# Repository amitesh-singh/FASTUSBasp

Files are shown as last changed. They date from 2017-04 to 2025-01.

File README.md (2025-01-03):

"Buy Me A Coffee" (https://www.buymeacoffee.com/singhamiteK)

### FASTUSBasp programmer for AVR Microcontrollers


This is the fast ISP programmer for AVR MCUs based on cheap stm32f103c8t6 aka `blue-pill` board with usb-to-serial support.

### Release

- v1.0.0:  https://github.com/amitesh-singh/FASTUSBasp/releases/tag/v1.0.0

#### FastUSBASPv2 board
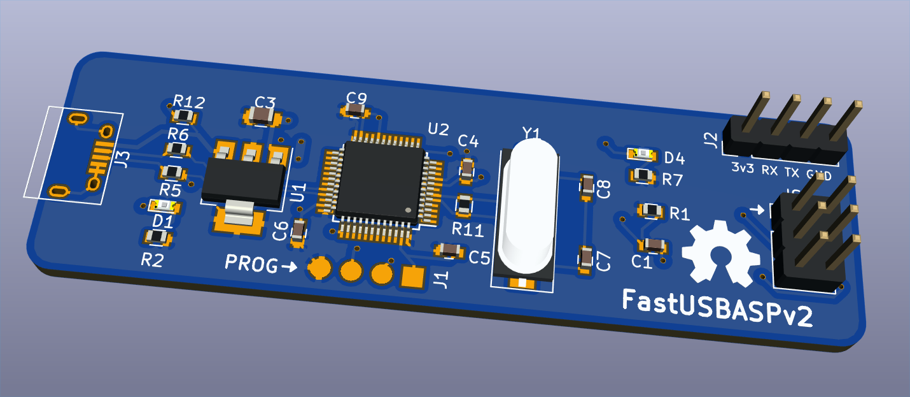
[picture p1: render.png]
FastUSBASPv2 board


#### Perf board
perfboard

### Correcting wrong pullup at USB D+

This blue pill board has wrong pullup resistor at usb D+ line.
You might need to fix it before using blue pill as an AVR programmer.
Refer to this guide: [http://amitesh-singh.github.io/stm32/2017/10/09/correcting-usbpullup-resistor.html][fixpullup-link]

### how to upload firmware

#### blue pill board with correct pullup at USB D+ line
 Download the binaries from https://github.com/amitesh-singh/FASTUSBasp/releases/tag/v1.0.0

If you have fixed the pullup at D+ line, use `fastusbasp.bin`
The pre-compiled binary is at `fastusbasp.bin`.

```shell
$ st-flash write fastusbasp.bin 0x08000000
```

#### blue pill board with wrong pullup at USB D+ line
In case, you did not fix the wrong pullup at D+ line, use
`fastusbasp-wrongpullup.bin` binary instead

```shell
$ st-flash write fastusbasp-wrongpullup.bin 0x08000000
```

### How to use

#### ISP connections

It uses SPI2 to communicate to AVR.

Blue pill | AVR
--------- | -------
PB15  |   MOSI
PB14  |   MISO
PB13  |   SCK
PA8   |   RST
5v or 3.3v |     5v
GND        |    GND

#### Serial connections
Serial ports are `PA10`(RX) and `PA9` (TX).
This can be used to debug AVR Microcontrollers.

Blue pill | AVR
--------- | -------
PA10      | TX
PA9       | RX

All pins SPI2(PB15, PB14, PB13), Serial(PA10, PA9) and RST(PA8) used are 5V tolerant.

#### udev rule

Refer to [udev/README.md](udev/README.md)

### On plugging to PC
#### Linux
When you plug this device to PC, you should get following message on`dmesg -wH`

```shell
[Jan20 13:31] usb 3-1.1: new full-speed USB device number 5 using xhci_hcd
[  +0.107774] usb 3-1.1: New USB device found, idVendor=16c0, idProduct=05dc
[  +0.000004] usb 3-1.1: New USB device strings: Mfr=1, Product=2, SerialNumber=3
[  +0.000002] usb 3-1.1: Product: fastusbasp
[  +0.000002] usb 3-1.1: Manufacturer: http://amitesh-singh.github.io
[  +0.000001] usb 3-1.1: SerialNumber: AARAV
[  +0.040797] cdc_acm 3-1.1:1.0: ttyACM0: USB ACM device
[  +0.000804] usbcore: registered new interface driver cdc_acm
[  +0.000000] cdc_acm: USB Abstract Control Model driver for USB modems and ISDN adapters
```

`/dev/ttyACM0` is the serial port.

#### Windows
- Download Zadig (https://zadig.akeo.ie/)
- Insert device to USB. Wait until windows can't install it.
- Launch Zadig
- Select in Zadig our device from ComboBox
- Select driver Type libusbK
- Press Install Driver
- Wait until Zadig is done with installing driver and that results into Windows to detect the device.

### Probe AVR

```shell
$ avrdude -c usbasp-clone -p m16

avrdude: AVR device initialized and ready to accept instructions

Reading | ################################################## | 100% 0.00s

avrdude: Device signature = 0x1e9403 (probably m16)

avrdude: safemode: Fuses OK (E:FF, H:D8, L:CF)

avrdude done.  Thank you.
```

### Upload program to AVR

```shell
$ avrdude -c usbasp-clone -p m16 -U flash:w:blink.hex

avrdude: AVR device initialized and ready to accept instructions

Reading | ################################################## | 100% 0.00s

avrdude: Device signature = 0x1e9403 (probably m16)
avrdude: NOTE: "flash" memory has been specified, an erase cycle will be performed
         To disable this feature, specify the -D option.
avrdude: erasing chip
avrdude: reading input file "blink.hex"
avrdude: input file blink.hex auto detected as Intel Hex
avrdude: writing flash (150 bytes):

Writing | ################################################## | 100% 0.02s

avrdude: 150 bytes of flash written
avrdude: verifying flash memory against blink.hex:
avrdude: load data flash data from input file blink.hex:
avrdude: input file blink.hex auto detected as Intel Hex
avrdude: input file blink.hex contains 150 bytes
avrdude: reading on-chip flash data:

Reading | ################################################## | 100% 0.01s

avrdude: verifying ...
avrdude: 150 bytes of flash verified

avrdude: safemode: Fuses OK (E:FF, H:D8, L:CF)

avrdude done.  Thank you.

```

### Read flash
```shell
$ avrdude -c usbasp-clone -p m16 -U flash:r:flash.bin:r

avrdude: AVR device initialized and ready to accept instructions

Reading | ################################################## | 100% 0.00s

avrdude: Device signature = 0x1e9403 (probably m16)
avrdude: reading flash memory:

Reading | ################################################## | 100% 0.33s

avrdude: writing output file "flash.bin"

avrdude: safemode: Fuses OK (E:FF, H:D8, L:CF)

avrdude done.  Thank you.

$ hexdump flash.bin
0000000 c029 0000 c02f 0000 c02d 0000 c02b 0000
0000010 c029 0000 c027 0000 c025 0000 c023 0000
0000020 c021 0000 c01f 0000 c01d 0000 c01b 0000
0000030 c019 0000 c017 0000 c015 0000 c013 0000
0000040 c011 0000 c00f 0000 c00d 0000 c00b 0000
0000050 c009 0000 2411 be1f e5cf e0d4 bfde bfcd
0000060 d002 c017 cfcd 9ab8 9ac0 ef2f ed83 e390
0000070 5021 4080 4090 f7e1 c000 0000 98c0 ef2f
0000080 ed83 e390 5021 4080 4090 f7e1 c000 0000
0000090 cfeb 94f8 cfff

```

### Flash Read/Write speed

Flash Write speed: 15 KBps
Flash Read Speed: 52.5 KBps

### Bit clock speed
`FASTUSBasp` starts out with a fast ISP clock frequency (default: 3 MHz),
   so the `-B bitclock` option might be required to achieve stable communication
in case target MCU `F_CPU` is bit low < 12MHz
#### Supported bitclock speed

- default (without -B): 3 MHz
- 1.5 MHz
- 750 KHz
- 375 KHz
- 187.5 KHz

### how to compile from source and upload the firmware
To build fastusbasp firmware from source code, follow below guidelines.

#### compile
Refer my post on how to setup stm32 devlopment environment on Arch linux.
http://amitesh-singh.github.io/stm32/2017/04/09/setting-stm32-dev-environment-arch-linux.html

Make sure you have compiled `libopencm3` library.

```shell
$ git clone --recurse-submodules https://github.com/amitesh-singh/FASTUSBasp
$ mkdir build
$ cd build
$ cmake ../
$ make
```
#### Upload the firmware
##### using STLINK
###### with st-flash
connect `st-link` programmer to `blue-pill` and upload the firmware

```shell
$ make fastusbasp-upload

```

###### with openocd

```shell
$ make fasusbasp-ocdupload

```

##### using serial port

Install `stm32flash` utility on linux.
To program `stm32f103` via USART, you need to set `BOOT0` as `1`
and leave `BOOT1` as `0`.

Connect any usb to uart converter device and connect PA9 to RXD and PA10 to TXD
and connect GND.

```shell
$ make fastusbasp-serialupload

```

### Links

- http://amitesh-singh.github.io/stm32/2017/05/21/FASTUSBasp-programmer-avr.html
- https://hackaday.io/project/21189-fastusbasp-programmer-for-avr

[fixpullup-link]: http://amitesh-singh.github.io/stm32/2017/10/09/correcting-usbpullup-resistor.html

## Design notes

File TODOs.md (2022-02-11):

### TODOs

- ~~support more speed.~~  
  avrdude -B 0.5/0.2 ..
- ~~Add kicad schematics for adapter board.~~
- ~~Add kicad gerber files for adapter board.~~
- ~~Add panelized pcb design and gerber files~~
- support TWI to support attiny
- Blink LED while flashing

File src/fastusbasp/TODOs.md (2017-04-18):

### TODOs

- ~~support more speed.~~  
  avrdude -B 0.5/0.2 ..
- ~~Add kicad schematics for adapter board.~~
- ~~Add kicad gerber files for adapter board.~~
- ~~Add panelized pcb design and gerber files~~
- Try to put 4 boards into 100x100mm area to save cost.

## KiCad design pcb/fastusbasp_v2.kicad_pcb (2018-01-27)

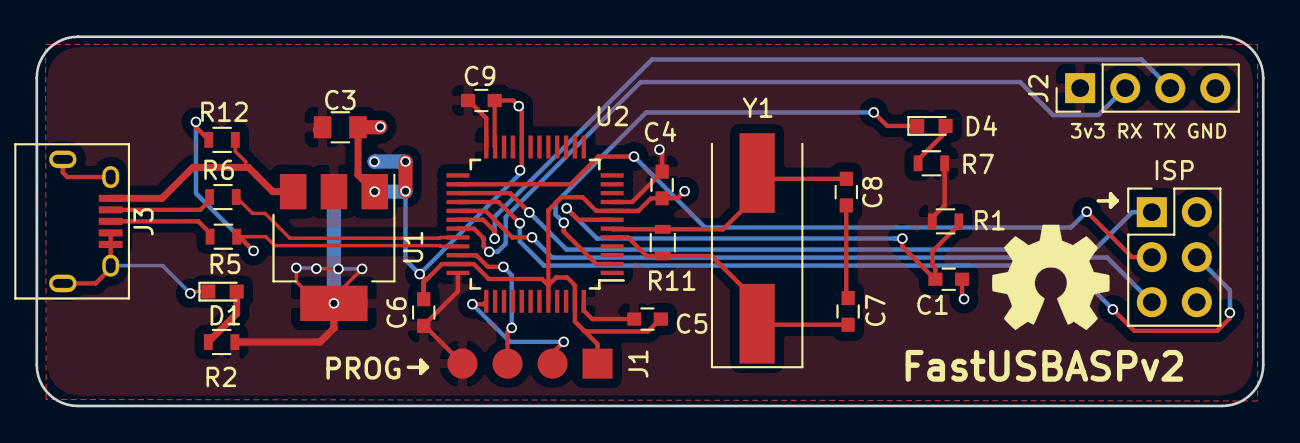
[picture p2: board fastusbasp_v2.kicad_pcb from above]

Board: 2 copper layers, 69.2 x 20.8 mm, 24 parts (0 on the bottom side), 22 nets.

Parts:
C1: 100nF; C_0603
C3: 10uF; C_0805
C4, C5, C6, C9: 100nf; C_0603
C7, C8: 20pF; C_0603
D1, D4: LED; LED_0603
ISP: AVR-ISP-6; Pin_Header_Straight_2x03_Pitch2.54mm
J1: PROG; Pin_Header_SMD_pads_1x04_pitch2.54mm
J2: CONN_01X04; Pin_Header_Straight_1x04_Pitch2.54mm
J3: USB_OTG; USB_Micro-B
R1: 10k; R_0603
R2, R7: 1k; R_0603
R5, R6: 20R; R_0603
R11: 1M; R_0603
R12: 1.5k; R_0603
U1: LM1117-3.3; SOT-223-3_TabPin2
U2: STM32F103C8Tx; LQFP-48_7x7mm_Pitch0.5mm
Y1: 16MHz; Crystal_SMD_HC49-SD

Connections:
+3V3: C3.1, C4.1, C5.1, C6.1, C9.1, J1.4, J2.1, R1.1, R2.2, R7.2, U1.2, U2.9, U2.24, U2.36, U2.48
+5V: J3.1, R12.2, U1.3
/D_N: R6.1, U2.32
/D_P: R5.1, R12.1, U2.33
/ISP_MISO: ISP.1, U2.27
/ISP_MOSI: ISP.4, U2.28
/ISP_RESET: ISP.5, U2.29
/ISP_SCK: ISP.3, U2.26
/PGM_LED: D4.1, U2.2
/RESET: C1.1, R1.2, U2.7
/RXD: J2.2, U2.31
/SWCLK: J1.2, U2.37
/SWDIO: J1.3, U2.34
/TXD: J2.3, U2.30
GND: C1.2, C3.2, C4.2, C5.2, C6.2, C9.2, D1.1, ISP.6, J1.1, J2.4, J3.4, J3.5, J3.6, U1.1, U2.8, U2.20, U2.23, U2.35, U2.44, U2.47
unnamed: C7.1, R11.1, U2.5, Y1.1
unnamed: C7.2, C8.2
unnamed: C8.1, R11.2, U2.6, Y1.2
unnamed: D1.2, R2.1
unnamed: D4.2, R7.1
unnamed: J3.2, R6.2
unnamed: J3.3, R5.2

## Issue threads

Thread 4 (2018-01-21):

Verify FASTUSBasp on Windows OS

amitesh-singh, 2018-01-21:
I don't own a windows PC at home. It would be nice if someone helps in validating FASTUSBasp on windows OS.

posystorage, 2018-02-02:
Hello, I try to burn the firmware (in stm32f103rct6, either fastusbasp.bin or fastusbasp-wrongpullup.bin) In the windows PC, the system shows usb get description failed (configuration descriptor is invalid)
This is the usb descriptor file
[fastusbasp  usb description.txt](https://github.com/amitesh-singh/FASTUSBasp/files/1688455/fastusbasp.usb.description.txt)
I think it may be missing the CDC Interface Descriptor and Endpoint Descriptor

I tried define USBDPLUS_WRONG_PULLUP=1
and modified the code here
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
However it also did not work

posystorage, 2018-02-02:
this is the usb enumeration process data which obtained by using the logic analyzer
[untitled.txt](https://github.com/amitesh-singh/FASTUSBasp/files/1688517/untitled.txt)

amitesh-singh, 2018-02-02:
Thanks.
do you have installed usb driver on windows?

Try following driver

http://zadig.akeo.ie/

posystorage, 2018-02-02:
I have installed the usb driver, and it works fine when using the "fastusbasp v1" firmware.

I get another PC which is  windows7 OS,it works fine，no matter which firmware it is（v1 or v2）
But v2 firmware does not work in  windows10

amitesh-singh, 2018-02-02:
Thanks for the detailed report.
Firmware V1 & V2 works on Windows 7 OS
Firmware V1 works on Windows 10 but Firmware V2 does not work on windows 10.
The difference between firmware V1 & v2 is the addition of USB-CDC(usb serial) into V2.

Sorry, I don't have any device running windows 7 or 10. This might needs to be checked by some Windows OS expert.

posystorage, 2018-02-02:
I analyzed the enumeration process and found that after the host requested the configuration descriptor, the device seems like returned the wrong configuration description data.
So when Windows received the wrong configuration descriptor, the system reset the usb bus, re-enumeration,  error again, after three consecutive errors, the enumeration failed.

another a problem, v2 firmware should enumerate two usb devices: serial port (VCP) and FASTUSBasp, but even in the Windows7 OS, it can only enumerate FASTUSBasp, but no serial port.

posystorage, 2018-02-02:
I think there is something wrong with the content of configuration descriptors
It is not standard, so that some OS do not recognize it, and some OS ignore these problems
for example：
v2 firmware configuration description
	bLength=0x0D
	bDescriptorType=0x02 CONFIGURATION
	wTotalLength=0x0094
	bNumInterfaces=0x03
	bConfigurationValue=0x01
	iConfiguration=0x00
	bmAttributes=0x80 Bus powered, Remote wakeup unsupported
	bMaxPower=0x32 100mA
	byte=0xD8
	byte=0x25
	byte=0x00
	byte=0x08
        bLength=0x08
	bDescriptorType=0x0B <unknown>
	byte=0x00
	byte=0x02
	byte=0x02
	byte=0x02
	byte=0x01
	byte=0x00
...........

USB standard configuration description should be
    /*Configuration Descriptor*/
    0x09,   /* bLength: Configuration Descriptor size */
    USB_CONFIGURATION_DESCRIPTOR_TYPE,      /* bDescriptorType: Configuration  0x02 */
    0x27,       /* wTotalLength:no of returned bytes */
    0x00,
    0x01,   /* bNumInterfaces: 1 interface */
    0x01,   /* bConfigurationValue: Configuration value */
    0x00,   /* iConfiguration: Index of string descriptor describing the configuration */
    0x80,   /* bmAttributes: self powered */
    0x32,   /* MaxPower 32 mA */
    /*Interface Descriptor*/
    0x09,   /* bLength: Interface Descriptor size */
    USB_INTERFACE_DESCRIPTOR_TYPE,  /* bDescriptorType: Interface */
    /* Interface descriptor type */
    0x00,   /* bInterfaceNumber: Number of Interface */
    0x00,   /* bAlternateSetting: Alternate setting */
    0x03,   /* bNumEndpoints: 3 endpoints used */
    0xff,   /* bInterfaceClass: Communication Interface Class */
    0xff,   /* bInterfaceSubClass: Abstract Control Model */
    0xff,   /* bInterfaceProtocol: Common AT commands */
    0x04,   /* iInterface: */
...........

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
Universal Serial Bus Specification Revision 2.0
page 265

I use the STM32F10x standard peripheral library and STM32F10x USB full-speed device library which is official library by STMicroelectronics ，so it is hard for me to understand the libopencm3 .It contains too many files, let me feel faint

So I hope to get your help, thanks.

amitesh-singh, 2018-02-04:
I got some pointers regarding fixing endpoints in usb cdc descriptor. I shall give it a try this week when i get time.

Thanks a lot to provide detailed debug informations.

amitesh-singh, 2018-02-08:
i pushed a small fix.

could you please try with this fix?
you do need to rebuild the project.

https://github.com/amitesh-singh/FASTUSBasp/commit/adf6f53b29b1322804abe90e93d6fa5eb1e4fa49
Please let me know if it solves the issue.

posystorage, 2018-02-09:
I just tried it.It did not work.😫

cdtsilva, 2019-02-26:
Can someone post a copy of the V1 firmware (no serial) that is supposed to work on Win10?

f4grx, 2019-03-12:
since this is a composite device, windows probably needs an .inf file to be able to manage both the fastusbasp (what is it ? HID?) AND the CDC ACM Virtual com port.

seaspacio, 2019-10-26:
can you please provide a V1 compiled firmware?

binarymaker, 2019-10-30:
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
In windows8 also not work. i tried master and cdc-fix branches.

Spider84, 2020-05-26:
Hello! I has fixed this issue: https://github.com/amitesh-singh/FASTUSBasp/pull/8

amitesh-singh, 2020-05-29:
Thanks to this patch, https://github.com/amitesh-singh/FASTUSBasp/commit/8e50587327878244815f05512673f850ab48613e,
by @Spider84 , FASTUSBasp is supported on Windows.

Spider84, 2020-05-29:
Glad to help. Thx for firmware. Very helped me to flash single AVR in my STM32 world :)

Closed 2020-05-29.

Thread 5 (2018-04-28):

Reset after programming

mkSaBtsy, 2018-04-28:
First to say: Great project.
FASTUSBasp is way faster than my AVRISPmkII clone which I couldn't get working under Win7-64 anyway.

Now my issue:
I'm using AVRDUDESS / Win7-64 to program an ATmega328p. Everything is working well.
But after any action the reset line stays low, keeping the microcontroller in reset state. What I'm doing wrong?
Please help.

amitesh-singh, 2018-04-28:
Hello
Thanks for the feedback. It seems like a bug.
I should set the RST pin to input on disconnect.

amitesh-singh, 2018-04-28:
Hello again,

i added the fix and updated the binaries too.
Please let me know if it fixes the issue.

https://github.com/amitesh-singh/FASTUSBasp/commit/8fc50ff744d3d3653f113068feb581d30c6b52c3

Thanks

mkSaBtsy, 2018-04-28:
Hello
Thanks a lot for the fast update. I flashed new firmware with ST-Link but unfortunately the RST line keeps low again.

mkSaBtsy, 2018-04-29:
Shouldn't you use
`rst.setMode(PinMode::INPUT, PinConfig::INPUT_FLOAT);`
instead of
`rst.setMode(PinMode::OUTPUT_2MHZ, PinConfig::INPUT_FLOAT);`
?
For pins mosi and sck this would apply too.
Can you change this and compile again? I'm new to ARM programming and not able to set up the project in Eclipse (under Windows) properly.

amitesh-singh, 2018-04-29:
Oops.. good catch .. i will update the code and binary.
Thanks.

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

amitesh-singh, 2018-04-30:
i updated the binaries and code. please check it again.

mkSaBtsy, 2018-04-30:
Dear Amitsh Singh
Now FastUSBasp works like a charm. Thumbs up.

In the mean time (since you uploaded the new binaries not necessary anymore) I tried to build FASTUSBasp on a fresh installed VM Ubuntu Linux. Do you know, if there's a difference between arch linux and ubuntu when disabling standard paths? Libopencm3 compiles without a problem but when linking FASTUSBasp make complains about missing libopencmw_stm32f1.ld file which is in FASTUSBasp directory.

Anyway. Many thanks for this great project.

amitesh-singh, 2018-05-01:
Or you can create separate md file (say windows.md) for guide.

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

mkSaBtsy, 2018-05-03:
Hello
I tried again to compile with fresh installed Ubuntu 18.04:

- [x] sudo apt-get update
- [x] sudo apt-get upgrade
- [x] sudo apt-get install git cmake make python gcc-arm-none-eabi
- [x] git clone https://github.com/libopencm3/libopencm3)
- [x] cd libopencm3
- [x] make
->compiles without problem

- [x] git clone https://github.com/amitesh-singh/FASTUSBasp
- [x] cd FASTUSBasp
- [x] nano config.cmake
->set(LIBOPENCM3_DIR "/home/mksabtsy/libopencm3")
- [x] cmake .
cmake . ends up in 4 warnings concerning deprecation (see attached screenshot)
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

- [x] make

-> as far as I can see, building works, but linking fails because of missing libopencm3_stm32f1.ld file.

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

libopencm3_stm32f1.ld is located in FASTUSBasp directory (.). I guess unlinking system paths does not work properly.

Now I'm short of time, but I could write a short instruction how to use FASTUSBasp with Win7/64. Maybe later even for Win10/64.
What about the pull request? Should I place my instructions there?

amitesh-singh, 2018-05-08:
Yes. please provide a pull request regarding the instructions for windows setup.

amitesh-singh, 2018-06-03:
Hi,

I fixed the compilation issue on Ubuntu.
Refer to https://github.com/amitesh-singh/FASTUSBasp/commit/e4bc3f48ea11e421ee3d1f94b6a9a09a7d714ec1

Closed 2018-04-28.

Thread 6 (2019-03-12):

Make it work on any machine

f4grx, 2019-03-12:
Hello,
wanted to build it, but:

```
me@machine~/code/fastusbasp $ cat config.cmake
# Always declare this before stm32-toolchain.cmake
#
set(MCU STM32F1)
set(LIBOPENCM3_DIR "/home/ami/repos/libopencm3")
set(SERIAL_PORT "/dev/ttyUSB0")
```
No chance this will work here :)

Can you include libopencm3 in your source tree, or manage it as a configurable dependency via, eg, a cmake variable?

thanks

f4grx, 2019-03-12:
OK, config.cmake works for this

however now I get this:
```
[ 75%] Linking CXX executable fastusbasp.elf
cd /home/user/code/fastusbasp/src && /usr/bin/cmake -E cmake_link_script CMakeFiles/fastusbasp.dir/link.txt --verbose=1
/home/user/toolchains/gcc-arm-none-eabi-7-2018-q2-update/bin/arm-none-eabi-g++    -fdata-sections -ffunction-sections -fno-exceptions -Wall --std=gnu++14 -Os -ggdb -mcpu=cortex-m3 -mthumb -mthumb-interwork -msoft-float -Wextra -Wshadow -Wredundant-decls    -flto -T /home/user/code/fastusbasp/libopencm3.ld -nostartfiles -lopencm3_stm32f1 -lc -specs=nosys.specs -Wl,--gc-sections -Wl,--relax CMakeFiles/fastusbasp.dir/main.cpp.obj  -o fastusbasp.elf  -L/home/user/code/libopencm3/lib  -L/home/user/code/libopencm3/lib/stm32/f1 -lopencm3_stm32f1 -L/home/user/code/fastusbasp/src/../lib/ ../lib/libstm32f1cpp.a -lopencm3_stm32f1
/home/user/toolchains/gcc-arm-none-eabi-7-2018-q2-update/bin/../lib/gcc/arm-none-eabi/7.3.1/../../../../arm-none-eabi/lib/thumb/v7-m/libc.a(lib_a-fini.o): In function `__libc_fini_array':
fini.c:(.text.__libc_fini_array+0x26): undefined reference to `_fini'
collect2: error: ld returned 1 exit status
src/CMakeFiles/fastusbasp.dir/build.make:95: recipe for target 'src/fastusbasp.elf' failed
```

It seems related to this:
https://bugs.launchpad.net/gcc-arm-embedded/+bug/1680293

Probably a problem in the linker script?

f4grx, 2019-03-12:
looks like this
http://www.chibios.com/forum/viewtopic.php?t=4172

Here is a patch that make it build with latest libopencm3 from git:

```
diff --git a/src/main.cpp b/src/main.cpp
index 7646406..d9b8644 100644
--- a/src/main.cpp
+++ b/src/main.cpp
@@ -651,3 +651,9 @@ config_setup(usbd_device *usb, uint16_t wValue)
                                   USB_REQ_TYPE_TYPE,
                                   isp_control_endpoint);
 }
+
+extern "C" {
+void _fini(void);
+}
+
+__attribute__((used)) void _fini(void) {}
```

amitesh-singh, 2019-05-08:
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

I'd already provided a guide which clearly mentions what needs to be done to compile.

amitesh-singh, 2019-05-08:
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

I think you are using a gcc version which has this bug.
mine is
_# arm-none-eabi-gcc --version
arm-none-eabi-gcc (Arch Repository) 8.3.0_

amitesh-singh, 2021-06-13:
woah!, I am also getting similar compilation errors now.
Thanks for the patch. I will add it

Closed 2021-06-13.

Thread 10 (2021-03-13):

avrdude error

Abubakr95, 2021-03-13:
the stm32 drivers are successfully installed and the device appears in the device manager on Windows10, but I get this error whenever I try to invoke avrdude using "avrdude -c usbasp-clone -p m8 "

avrdude: error: could not find USB device with vid=0x16c0 pid=0x5dc

Driver Management concluded the process to install driver fastusbasp_(interface_0).inf_amd64_4652f43e1d1cad1d\fastusbasp_(interface_0).inf for Device Instance ID USB\VID_16C0&PID_05DC&MI_00\7&2666295D&0&0000 with the following status: 0x0

Abubakr95, 2021-03-14:
it turns out the problem is with avrdude for windows, it's not working properly.
the solution was to use khazama GUI and set the spi speed to either 187.5kHz or 375kHz ... and voila all looks good, thanks

Closed 2021-03-14.

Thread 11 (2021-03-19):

Firmware for ST-Link clone

trembel, 2021-03-19:
Hi,

I've two question to your firmware:
- Is it possible to directly flash it onto a ST-Link clone or are there some small changes needed? https://www.hobbiton.be/blog/repurpose-stlink/
- Does it support the TPI programming for the small attiny4/5/9/10?
Best, trembel

trembel, 2021-03-19:
Seems as if only a small wire is needed from PB15 to PB8, and removing R7, R8, R12.
And some smaller fw changes, e.g. to set RST to PB6 and LED to PA9..

But the question for me is if it supports TPI?

amitesh-singh, 2021-04-26:
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

no, it does not support TPI

Closed 2021-04-26.

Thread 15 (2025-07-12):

failed to recognize bluepill as fastusbasp in dmesg

robgal519, 2025-07-12:
I tried to flash the release binaries on the blue pill using st-link. The flashing seemed successful, but when I connected blue pill to my linux pc via usb, I did not get the desired output on dmesg.

I got:
```
[Jul12 13:38] usb 3-3: new full-speed USB device number 33 using xhci_hcd
[  +0.114009] usb 3-3: device descriptor read/64, error -71
[  +0.222006] usb 3-3: device descriptor read/64, error -71
[  +0.215923] usb 3-3: new full-speed USB device number 34 using xhci_hcd
[  +0.114027] usb 3-3: device descriptor read/64, error -71
[  +0.221994] usb 3-3: device descriptor read/64, error -71
[  +0.102034] usb usb3-port3: attempt power cycle
[  +0.379969] usb 3-3: new full-speed USB device number 35 using xhci_hcd
[  +0.000195] usb 3-3: Device not responding to setup address.
[  +0.203967] usb 3-3: Device not responding to setup address.
[  +0.207819] usb 3-3: device not accepting address 35, error -71
[  +0.000062] usb 3-3: WARN: invalid context state for evaluate context command.
[  +0.113961] usb 3-3: new full-speed USB device number 36 using xhci_hcd
[  +0.000203] usb 3-3: Device not responding to setup address.
[  +0.205894] usb 3-3: Device not responding to setup address.
[  +0.207864] usb 3-3: device not accepting address 36, error -71
[  +0.000113] usb 3-3: WARN: invalid context state for evaluate context command.
[  +0.000036] usb usb3-port3: unable to enumerate USB device
```

I use ubuntu:
```
robert@robert-ThinkPad-T440p:~$ uname -a
Linux robert-ThinkPad-T440p 6.11.0-29-generic #29~24.04.1-Ubuntu SMP PREEMPT_DYNAMIC Thu Jun 26 14:16:59 UTC 2 x86_64 x86_64 x86_64 GNU/Linux
```

I also tried to build the project from source, this was succesful, and again I flashed the firmware on bluepill, but I got hte same issue with dmesg when I connected flashed device via usb

amitesh-singh, 2025-09-07:
The binaries are quite old but it should have just worked. I am going to update the binaries and release them.

amitesh-singh, 2025-09-07:
it works at my end.

```
[  +7.112676] usb 3-5.3.2: new full-speed USB device number 61 using xhci_hcd
[  +0.111455] usb 3-5.3.2: New USB device found, idVendor=16c0, idProduct=05dc, bcdDevice= 2.00
[  +0.000005] usb 3-5.3.2: New USB device strings: Mfr=1, Product=2, SerialNumber=3
[  +0.000001] usb 3-5.3.2: Product: fastusbasp
[  +0.000001] usb 3-5.3.2: Manufacturer: http://amitesh-singh.github.io
[  +0.000001] usb 3-5.3.2: SerialNumber: 1C48FA2F0000
[  +0.009005] cdc_acm 3-5.3.2:1.0: ttyACM0: USB ACM device

```

amitesh-singh, 2025-09-07:
Please try with https://github.com/amitesh-singh/FASTUSBasp/releases/tag/v1.0.1

Closed 2025-09-07.

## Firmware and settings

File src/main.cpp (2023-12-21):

/*
 * FASTUSBasp v2 - Fastest programmer for AVR
 * Copyright (C) 2018  Amitesh Singh <singh.amitesh@gmail.com>
 *
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
 * You should have received a copy of the GNU General Public License
 * along with this program.  If not, see <http://www.gnu.org/licenses/>.
 */

#include "rcc.h"
#include "pin.h"
#include "delay.h"
#include "fastserial.h"

#include "usb/descriptor.h"
#include "dma/dmabuffer1.h"
#include <string.h>
#include "queue.h"
#include <libopencm3/stm32/desig.h>

#if USBDPLUS_WRONG_PULLUP == 1

#include "usb/util.h"

#endif

extern "C"
{
   #include <libopencm3/usb/cdc.h>
}

#ifdef DEBUG
#include "serial.h"
#endif

//avrdude commands on control ep
#define USBASP_FUNC_CONNECT          1
#define USBASP_FUNC_DISCONNECT       2
#define USBASP_FUNC_TRANSMIT         3
#define USBASP_FUNC_READFLASH        4
#define USBASP_FUNC_ENABLEPROG       5
#define USBASP_FUNC_WRITEFLASH       6
#define USBASP_FUNC_READEEPROM       7
#define USBASP_FUNC_WRITEEEPROM      8
#define USBASP_FUNC_SETLONGADDRESS   9
#define USBASP_FUNC_SETISPSCK        10
#define USBASP_FUNC_GETCAPABILITIES  127

// programming state
#define PROG_STATE_IDLE         0
#define PROG_STATE_WRITEFLASH   1
#define PROG_STATE_READFLASH    2
#define PROG_STATE_READEEPROM   3
#define PROG_STATE_WRITEEEPROM  4

// Block mode flags
#define PROG_BLOCKFLAG_FIRST    1
#define PROG_BLOCKFLAG_LAST     2

static uint8_t prog_new_mode = 0;
static uint32_t prog_address;
static uint16_t prog_nbytes = 0;
static uint8_t prog_state = PROG_STATE_IDLE;
static uint16_t prog_pagesize;
static uint8_t prog_blockflags;
static uint8_t prog_pagecounter;

#include "isp.h"

static char serial[] = "0123456789AB";
static const char *usb_strings[] =
{
   "http://amitesh-singh.github.io", //manufacturer
   "fastusbasp", //product
   serial // Serial number
};

const static auto dev_desc = usb::device_desc(
   0x0200, //bcdUSB = 2.00 
   0xEF, //Class We will define this later in interface classes
   2, //SubClass
   1, //Protocol
   64, //Max Pkt size
   0x16c0, //ven ID
   0x05dc, //dev ID
   0x0200, //bcdDevice 1.04
   1,
   2,
   3,
   1
);

static const struct {
     struct usb_cdc_header_descriptor header;
     struct usb_cdc_call_management_descriptor call_mgmt;
     struct usb_cdc_acm_descriptor acm;
     struct usb_cdc_union_descriptor cdc_union;
} __attribute__((packed)) cdcacm_functional_descriptors = {
     .header = {
          .bFunctionLength = sizeof(struct usb_cdc_header_descriptor),
          .bDescriptorType = CS_INTERFACE,
          .bDescriptorSubtype = USB_CDC_TYPE_HEADER,
          .bcdCDC = 0x0110,
     },
     .call_mgmt = {
          .bFunctionLength =
             sizeof(struct usb_cdc_call_management_descriptor),
          .bDescriptorType = CS_INTERFACE,
          .bDescriptorSubtype = USB_CDC_TYPE_CALL_MANAGEMENT,
          .bmCapabilities = 0,
          .bDataInterface = 1,
     },
     .acm = {
          .bFunctionLength = sizeof(struct usb_cdc_acm_descriptor),
          .bDescriptorType = CS_INTERFACE,
          .bDescriptorSubtype = USB_CDC_TYPE_ACM,
          .bmCapabilities = 2, // SET_LINE_CODING supported
     },
     .cdc_union = {
          .bFunctionLength = sizeof(struct usb_cdc_union_descriptor),
          .bDescriptorType = CS_INTERFACE,
          .bDescriptorSubtype = USB_CDC_TYPE_UNION,
          .bControlInterface = 0,
          .bSubordinateInterface0 = 1,
     }
};

/*
 * This notification endpoint isn't implemented. According to CDC spec it's
 * optional, but its absence causes a NULL pointer dereference in the
 * Linux cdc_acm driver
 */
static const auto comm_endp_desc = usb::endpoint_desc(
   0x81,
   USB_ENDPOINT_ATTR_INTERRUPT,
   16,
   255
   );
static const usb_endpoint_descriptor comm_endp[] = {comm_endp_desc};

static const usb_interface_descriptor comm_iface[] =
{
   usb::interface_desc(0, 0, 1,
                       USB_CLASS_CDC, USB_CDC_SUBCLASS_ACM, USB_CDC_PROTOCOL_AT,
                       0, comm_endp,
                       &cdcacm_functional_descriptors, sizeof(cdcacm_functional_descriptors))
};

static const auto ep2_out = usb::endpoint_desc(
   0x02,
   USB_ENDPOINT_ATTR_BULK,
   64,
   0);

static const auto ep3_in = usb::endpoint_desc(
   0x82,
   USB_ENDPOINT_ATTR_BULK,
   64,
   0);

static const usb_endpoint_descriptor data_endp[] = {ep2_out, ep3_in};

static const usb_interface_descriptor data_iface[] =
{
   usb::interface_desc(1, 0, 2, USB_CLASS_DATA, 0, 0, 0, data_endp)
};

static const auto cdc_acm_interface_association =
usb::ifaceassoc_desc(0, 2, USB_CLASS_CDC, USB_CDC_SUBCLASS_ACM, USB_CDC_PROTOCOL_AT, 0);

//Vendor class interface -
// defines 0xFF as usb vendor class and interface number which is 2 in ifaces
static const usb_interface_descriptor vendor_iface[] =
{
   usb::interface_desc(2, 0, 0, USB_CLASS_VENDOR, 0, 0, 0, nullptr)
};

static const usb_interface ifaces[] =
{
   // CDC
   usb::interface(nullptr, 1, &cdc_acm_interface_association, comm_iface),
   usb::interface(nullptr, 1, nullptr, data_iface),

   // vendor class
   usb::interface(nullptr, 1, nullptr, vendor_iface)
};

static const auto config = usb::config_desc(3, 1, 0, 0x80, 0x32, ifaces);

static usbd_device *usbd_dev;

static void config_setup(usbd_device *usb, uint16_t wValue);
uint8_t ret;
static pin led;

static uint8_t usbdControlBuf[512];

static void
_serial1_rx_callback(volatile uint8_t &d)
{
   ret = d;
   usbd_ep_write_packet(usbd_dev, 0x82, &ret, 1);
}

static uint8_t usb_serial_databuf[64];
struct txbuf
{
  uint8_t buffer[64];
  uint8_t len;
} __attribute__((__packed__));

static txbuf TXBUF[16];
class dmaqueue: public util::queue<txbuf>
{
 public:
    dmaqueue(int n): util::queue<txbuf>(n, TXBUF) {}
    void push(uint8_t *buf, int len)
      {
         if (_count < _maxitems)
           {
              dma1Ch1Buffer.copy(_data[_back].buffer, buf, len);
               while (!dma1Ch1Buffer.transferred)
               {
                  __asm__ volatile ("nop");
               }
              _data[_back].len = len;
              ++_back;
              ++_count;
              if (_back >= _maxitems)
                {
                   _back = 0;
                }
           }
      }
};

void *__dso_handle = nullptr;

//thanks to @f4grx, https://github.com/f4grx
extern "C" {
void _fini(void); //prevent C++ function name mangling
}
__attribute__((used)) void _fini(void) {} //make the linker happy


dmaqueue q(16);

#ifdef DEBUG
serial s2;
#endif

static void IntToString (uint32_t value , char *pbuf , size_t len)
{
  for( size_t idx = 0 ; idx < len ; idx ++)
  {
    if( ((value >> 28)) < 0xA )
    {
      pbuf[idx] = (value >> 28) + '0';
    }
    else
    {
      pbuf[idx] = (value >> 28) + 'A' - 10;
    }

    value = value << 4;
  }
}

static void Get_SerialNum(void)
{
  uint32_t Device_Serial[3];

  desig_get_unique_id(Device_Serial);

  Device_Serial[0] += Device_Serial[2];

  if (Device_Serial[0] != 0)
  {
    IntToString (Device_Serial[0], serial, 8);
    IntToString (Device_Serial[1], serial+8, 4);
  }
}

int
main()
{
   //RCC::defaultClockSetup();
   RCC::clockAt48mhz();

   //set up all the clocks
   RCC::enable(INBUILT_LED_RCC);
   RCC::enable(ISP_PORT_RCC);
   RCC::enable(ISP_RST_RCC);
   RCC::enable(ISP_BUS_RCC);

   //setup onboard led 
   led.assign(INBUILT_LED_PORT, INBUILT_LED);
   led.setMode(PinMode::OUTPUT_2MHZ, PinConfig::OUTPUT_PUSHPULL);
   led.on();

#ifdef DEBUG
   s2.begin(SerialType::Serial2, 9600);
#endif

   time::enable();

   fastserial1.setRxcb(_serial1_rx_callback);

   //This is required if proper pullup is not present at D+ line.
   // This is must for chinese stm32f103c8t6 aka "blue pill"
   // set USBDPLUS_WRONG_PULLUP to 1 if blue pill has wrong pullup at D+ line
   // This code is disabled by default.
#if USBDPLUS_WRONG_PULLUP == 1
     {
        pin usbdplus(GPIOA, GPIO12);
        usbdplus.setMode(PinMode::OUTPUT_50MHZ, PinConfig::OUTPUT_PUSHPULL);
        usbdplus.off();
        time::delay(1);
     }
#endif

   //usb setup code
   Get_SerialNum();

   RCC::enable(RCC_USB);

   usbd_dev = usbd_init(&st_usbfs_v1_usb_driver, &dev_desc, &config,
                        usb_strings, 3, usbdControlBuf, sizeof(usbdControlBuf));
   usbd_register_set_config_callback(usbd_dev, config_setup);

   uint8_t in_transfer = 0;
   while (1)
     {
           if (fastserial1.transferred) {
               if (in_transfer) {
                       q.pop();
                       in_transfer = 0;
               }

               if (!q.empty())
               {
                auto buf = q.front();
                if (buf.len>0) {
                        fastserial1.write(buf.buffer, buf.len);
                        in_transfer = 1;
                } else {
                        q.pop();
                }
          }
           }
        usbd_poll(usbd_dev);
     }

   return 0;
}

static void
_serial_usb_data_in_cb(usbd_device *usb, uint8_t ep)
{
   (void) ep;
   int len;

   len = usbd_ep_read_packet(usb, 0x02, usb_serial_databuf, 64);
   if (len)
     {
        q.push(usb_serial_databuf, len);
     }
}

static void
usbuart_set_line_coding(struct usb_cdc_line_coding *coding)
{
   fastserial1.setBaudrate(coding->dwDTERate);

   if (coding->bParityType)
     fastserial1.setDatabits(coding->bDataBits + 1);
   else
     fastserial1.setDatabits(coding->bDataBits);

   switch(coding->bCharFormat)
     {
      case 0:
         fastserial1.setStopbits(USART_STOPBITS_1);
         break;
      case 1:
         fastserial1.setStopbits(USART_STOPBITS_1_5);
         break;
      case 2:
         fastserial1.setStopbits(USART_STOPBITS_2);
         break;
     }

   switch(coding->bParityType)
     {
      case 0:
         fastserial1.setParity(USART_PARITY_NONE);
         break;
      case 1:
         fastserial1.setParity(USART_PARITY_ODD);
         break;
      case 2:
         fastserial1.setParity(USART_PARITY_EVEN);
         break;
     }
}

static struct usb_cdc_line_coding _usb_cdc_line_coding_backup;

static enum usbd_request_return_codes
serial_control_request(usbd_device *usb, struct usb_setup_data *req, uint8_t **buf,
                       uint16_t *len, void (**complete)(usbd_device *,
                       struct usb_setup_data *))
{
   (void) complete;
   (void) usb;
   (void) req;

   switch (req->bRequest)
     {
      case USB_CDC_REQ_SET_CONTROL_LINE_STATE:
           {
              /*
               * This Linux cdc_acm driver requires this to be implemented
               * even though it's optional in the CDC spec, and we don't
               * advertise it in the ACM functional descriptor.
               */
//              char local_buf[10];
//              usb_cdc_notification *notif = (usb_cdc_notification *)local_buf;
//
//              /* We echo signals back to host as notification. */
//              notif->bmRequestType = 0xA1;
//              notif->bNotification = USB_CDC_NOTIFY_SERIAL_STATE;
//              notif->wValue = 0;
//              notif->wIndex = 0;
//              notif->wLength = 2;
//              local_buf[8] = req->wValue & 3;
//              local_buf[9] = 0;
//              usbd_ep_write_packet(usbd_dev, 0x82, local_buf, 10);

              return USBD_REQ_HANDLED;
           }
      case USB_CDC_REQ_SET_LINE_CODING:
           {
              if (*len < sizeof(struct usb_cdc_line_coding))
                return USBD_REQ_NOTSUPP;

              struct usb_cdc_line_coding *usbCdcLineCondig =(struct usb_cdc_line_coding *)*buf;
              memcpy(&_usb_cdc_line_coding_backup, usbCdcLineCondig,
                     sizeof(_usb_cdc_line_coding_backup));

              fastserial1.begin(usbCdcLineCondig->dwDTERate);
              dma1Ch1Buffer.begin();
              usbuart_set_line_coding(&_usb_cdc_line_coding_backup);

              return USBD_REQ_HANDLED;
           }
      case 0x21: //USB_CDC_REQ_GET_LINE_CODING https://www.silabs.com/documents/public/application-notes/AN758.pdf page 3
      	  {
      		  if (req->wLength<sizeof(_usb_cdc_line_coding_backup))
      			return USBD_REQ_NOTSUPP;

      		  //Windows get Error when zero
			  if (_usb_cdc_line_coding_backup.bDataBits==0)
				_usb_cdc_line_coding_backup.bDataBits = 8;
			  if (_usb_cdc_line_coding_backup.dwDTERate==0)
			  	_usb_cdc_line_coding_backup.dwDTERate = 115200U;

      		  memcpy(*buf, &_usb_cdc_line_coding_backup, *len = sizeof(_usb_cdc_line_coding_backup));

      	  	  return USBD_REQ_HANDLED;
      	  }
     }
   return USBD_REQ_NEXT_CALLBACK;
}

static uint16_t
read_usb(uint8_t* data, uint16_t len)
{
   uint16_t i;

   // check if programmer is in correct read state
   if ((prog_state != PROG_STATE_READFLASH)
       && (prog_state != PROG_STATE_READEEPROM))
     {
        return 0xff;
     }

   // fill packet ISP mode
   for (i = 0; i < len; i++)
     {
        if (prog_state == PROG_STATE_READFLASH)
          {
             data[i] = read_flash(prog_address);
          }
        else
          {
             data[i] = read_eeprom(prog_address);
          }
        prog_address++;
     }

   // last packet?
   if (len < 8)
     {
        prog_state = PROG_STATE_IDLE;
     }

   return len;
}


static uint16_t
write_usb(uint8_t* data, uint16_t len)
{
   uint8_t retVal = 0;
   uint16_t i;

   /* check if programmer is in correct write state */
   if ((prog_state != PROG_STATE_WRITEFLASH)
       && (prog_state != PROG_STATE_WRITEEEPROM))
     {
        return 0xff;
     }

   for (i = 0; i < len; i++) {

        if (prog_state == PROG_STATE_WRITEFLASH)
          {
             /* Flash */
             if (prog_pagesize == 0)
               {
                  /* not paged */
                  write_flash(prog_address, data[i], 1);
               }
             else
               {
                  /* paged */
                  write_flash(prog_address, data[i], 0);
                  prog_pagecounter--;
                  if (prog_pagecounter == 0)
                    {
                       flush_page(prog_address, data[i]);
                       prog_pagecounter = prog_pagesize;
                    }
               }
          }
        else
          {
             // EEPROM 
             write_eeprom(prog_address, data[i]);
          }

        prog_nbytes--;

        if (prog_nbytes == 0)
          {
             prog_state = PROG_STATE_IDLE;
             if ((prog_blockflags & PROG_BLOCKFLAG_LAST)
                 && (prog_pagecounter != prog_pagesize))
               {
                  /* last block and page flush pending, so flush it now */
                  flush_page(prog_address, data[i]);
               }

             retVal = 1; // Need to return 1 when no more data is to be received
          }

        prog_address++;
   }

   return retVal;
}

static enum usbd_request_return_codes
isp_control_endpoint(usbd_device *usb, struct usb_setup_data *req,
                     uint8_t **buf, uint16_t *len,
                     void (**complete)(usbd_device *, struct usb_setup_data *))
{
   (void) usb;
   (void) req;
   (void) complete;

   if ((req->bmRequestType & 0x7F) != USB_REQ_TYPE_VENDOR)
     return USBD_REQ_NEXT_CALLBACK;
   *len = 0;

   if (req->bRequest == USBASP_FUNC_CONNECT)
     {
        //disable USART
        fastserial1.end();
        led.off(); //PC13 led on
        isp_connect();
        prog_new_mode = 0;
     }
   else if (req->bRequest == USBASP_FUNC_DISCONNECT)
     {
        led.on(); //PC13 led off
        isp_disconnect();
        //enable USART again here.
        fastserial1.rebegin();
        dma1Ch1Buffer.begin();
        usbuart_set_line_coding(&_usb_cdc_line_coding_backup);
     }
   else if (req->bRequest == USBASP_FUNC_GETCAPABILITIES)
     {
        (*len) = 0;
        (*buf)[0] = 0;
     }
   else if (req->bRequest == USBASP_FUNC_TRANSMIT)
     {
        (*buf)[0] = transmit(req->wValue & 0xFF);
        (*buf)[1] = transmit(req->wValue >> 8);
        (*buf)[2] = transmit(req->wIndex & 0xFF);
        (*buf)[3] = transmit(req->wIndex >> 8);

        (*len) = 4;
     }
   else if (req->bRequest == USBASP_FUNC_SETISPSCK)
     {
        set_ack_option(req->wValue);

        (*buf)[0] = 0;
        (*len) = 1;
     }
   else if (req->bRequest == USBASP_FUNC_ENABLEPROG)
     {
        (*buf)[0] = enter_into_prog_mode();
        (*len) = 1;
     }
   else if (req->bRequest == USBASP_FUNC_READFLASH)
     {
        if (!prog_new_mode)
          prog_address = req->wValue;

        prog_nbytes = req->wLength;
        prog_state = PROG_STATE_READFLASH;
        (*len) = read_usb((*buf), prog_nbytes);
     }
   else if (req->bRequest == USBASP_FUNC_WRITEFLASH)
     {
        if (!prog_new_mode)
          prog_address = req->wValue;

        prog_pagesize = req->wIndex & 0xFF;
        prog_blockflags = (req->wIndex >> 8) & 0x0F;
        prog_pagesize += ((req->wIndex >> 8) & 0xF0) << 4;
        if (prog_blockflags & PROG_BLOCKFLAG_FIRST)
          {
             prog_pagecounter = prog_pagesize;
          }
        prog_nbytes = req->wLength;
        prog_state = PROG_STATE_WRITEFLASH;
        (*len) = write_usb((*buf), prog_nbytes);
     }
   else if (req->bRequest == USBASP_FUNC_READEEPROM)
     {
        if (!prog_new_mode)
          prog_address = req->wValue;
        prog_nbytes = req->wLength;
        prog_state = PROG_STATE_READEEPROM;
        (*len) = read_usb((*buf), prog_nbytes);
     }
   else if (req->bRequest == USBASP_FUNC_WRITEEEPROM)
     {
        if (!prog_new_mode)
          prog_address = req->wValue;

        prog_pagesize = 0;
        prog_blockflags = 0;
        prog_nbytes = req->wLength;
        prog_state = PROG_STATE_WRITEEEPROM;
        (*len) = write_usb((*buf), prog_nbytes);
     }
   else if (req->bRequest == USBASP_FUNC_SETLONGADDRESS)
     {
        // set new mode of address delivering (ignore address delivered in commands)
        prog_new_mode = 1;
        // set new address
        prog_address = (req->wIndex << 16) | req->wValue;
        (*len) = 0;
     }

   return USBD_REQ_HANDLED;
}

static void
config_setup(usbd_device *usb, uint16_t wValue)
{
   (void) usb;
   (void) wValue;

   usbd_ep_setup(usbd_dev, 0x81, USB_ENDPOINT_ATTR_INTERRUPT, 16, nullptr);
   usbd_ep_setup(usbd_dev, 0x02, USB_ENDPOINT_ATTR_BULK, 64, _serial_usb_data_in_cb);
   usbd_ep_setup(usbd_dev, 0x82, USB_ENDPOINT_ATTR_BULK, 64, nullptr);

   usbd_register_control_callback(usbd_dev,
                                  USB_REQ_TYPE_CLASS | USB_REQ_TYPE_INTERFACE,
                                  USB_REQ_TYPE_TYPE | USB_REQ_TYPE_RECIPIENT,
                                  serial_control_request);

   usbd_register_control_callback(usbd_dev,
                                  USB_REQ_TYPE_VENDOR,
                                  USB_REQ_TYPE_TYPE,
                                  isp_control_endpoint);
}

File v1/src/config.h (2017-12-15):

#ifndef _CONFIG_H
#define _CONFIG_H

#define INBUILT_LED GPIO13
#define INBUILT_LED_PORT GPIOC
#define INBUILT_LED_RCC RCC_GPIOC

#define ISP_BUS SPI2
#define ISP_BUS_RCC RCC_SPI2

#define ISP_PORT_RCC RCC_GPIOB
#define ISP_PORT GPIOB
#define ISP_MOSI GPIO15
#define ISP_MISO GPIO14
#define ISP_SCK  GPIO13

#define ISP_RST_RCC RCC_GPIOA
#define ISP_RST_PORT GPIOA
#define ISP_RST GPIO8

//define this to 1, if blue pill has wrong pull up at USB D+ line
#define USBDPLUS_WRONG_PULLUP 0

#endif

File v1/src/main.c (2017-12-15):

/*
 * FASTUSBasp - Fastest programmer for AVR
 * Copyright (C) 2017  Amitesh Singh <singh.amitesh@gmail.com>
 *
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
 * You should have received a copy of the GNU General Public License
 * along with this program.  If not, see <http://www.gnu.org/licenses/>.
 */

//#define DEBUG

#include <libopencm3/cm3/common.h>
#include <libopencm3/stm32/rcc.h>
#include <libopencm3/stm32/gpio.h>
#include <libopencm3/stm32/usart.h>
#include <libopencm3/cm3/nvic.h>
#include <libopencm3/stm32/flash.h>
#include "config.h"

#include <stdio.h>
#include <stdlib.h>
#include <libopencm3/usb/usbd.h>

#ifdef DEBUG
#include "usart1.h"
#endif

#include "sleep.h"
#include "usbdevice.h"

void rcc_clock_setup_in_hse_8mhz_out_48mhz(void)
{
   /* Enable internal high-speed oscillator. */
   rcc_osc_on(RCC_HSI);
   rcc_wait_for_osc_ready(RCC_HSI);

   /* Select HSI as SYSCLK source. */
   rcc_set_sysclk_source(RCC_CFGR_SW_SYSCLKSEL_HSICLK);

   /* Enable external high-speed oscillator 8MHz. */
   rcc_osc_on(RCC_HSE);
   rcc_wait_for_osc_ready(RCC_HSE);
   rcc_set_sysclk_source(RCC_CFGR_SW_SYSCLKSEL_HSECLK);

   /*
    * Set prescalers for AHB, ADC, ABP1, ABP2.
    */
   rcc_set_hpre(RCC_CFGR_HPRE_SYSCLK_NODIV);    /* Set. 48MHz Max. 72MHz */
   rcc_set_adcpre(RCC_CFGR_ADCPRE_PCLK2_DIV4);  /* Set. 12MHz Max. 14MHz */
   rcc_set_ppre1(RCC_CFGR_PPRE1_HCLK_DIV2);    /* Set. 24MHz Max. 36MHz */
   rcc_set_ppre2(RCC_CFGR_PPRE2_HCLK_NODIV);    /* Set. 48MHz Max. 72MHz */
   rcc_set_usbpre(RCC_CFGR_USBPRE_PLL_CLK_NODIV); /* Set 48Mhz, Max: 48Mhz */

   /*
    * Sysclk runs with 24MHz -> 0 waitstates.
    * 0WS from 0-24MHz
    * 1WS from 24-48MHz
    * 2WS from 48-72MHz
    */
   flash_set_ws(FLASH_ACR_LATENCY_1WS);

   /*
    * Set the PLL multiplication factor to 3.
    * 8MHz (external) * 6 (multiplier) = 48MHz
    */
   rcc_set_pll_multiplication_factor(RCC_CFGR_PLLMUL_PLL_CLK_MUL6);

   /* Select HSE as PLL source. */
   rcc_set_pll_source(RCC_CFGR_PLLSRC_HSE_CLK);

   /*
	 * External frequency undivided before entering PLL
	 * (only valid/needed for HSE).
	 */
   rcc_set_pllxtpre(RCC_CFGR_PLLXTPRE_HSE_CLK);

   /* Enable PLL oscillator and wait for it to stabilize. */
   rcc_osc_on(RCC_PLL);
   rcc_wait_for_osc_ready(RCC_PLL);

   /* Select PLL as SYSCLK source. */
   rcc_set_sysclk_source(RCC_CFGR_SW_SYSCLKSEL_PLLCLK);

   /* Set the peripheral clock frequencies used */
   rcc_ahb_frequency = 48000000;
   rcc_apb1_frequency = 24000000;
   rcc_apb2_frequency = 48000000;
}

int
main()
{
   //set STM32 to 48 MHz using ext. clock (HSE)
   rcc_clock_setup_in_hse_8mhz_out_48mhz();


   // set up all the clocks here
   rcc_periph_clock_enable(ISP_PORT_RCC);
   rcc_periph_clock_enable(ISP_RST_RCC);
   rcc_periph_clock_enable(INBUILT_LED_RCC);
   rcc_periph_clock_enable(ISP_BUS_RCC);

   inbuilt_led_init();

#ifdef DEBUG
   usart1_setup();
#endif

   clock_setup();

   //This is required if proper pullup is not present at D+ line.
   // This is must for chinese stm32f103c8t6 aka "blue pill"
   // set USBDPLUS_WRONG_PULLUP to 1 if blue pill has wrong pullup at D+ line
   // This code is disabled by default.
#if USBDPLUS_WRONG_PULLUP == 1
   gpio_set_mode(GPIOA, GPIO_MODE_OUTPUT_2_MHZ,
                 GPIO_CNF_OUTPUT_PUSHPULL, GPIO12);
   gpio_clear(GPIOA, GPIO12);
   msleep(5);
#endif

   // USB initialization
   usbd_dev = usbd_init(&st_usbfs_v1_usb_driver, &dev_descr, &config,
                        usb_strings, 2, usbd_control_buffer,
                        sizeof(usbd_control_buffer));
   usbd_register_set_config_callback(usbd_dev, set_config);

#ifdef DEBUG
   usart1_println("usb init");
#endif

   while(1)
     {
        usbd_poll(usbd_dev);
     }
}

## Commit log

2017-04-15 sleep: fix the bug
    the timer is now synced with 48MHz F_CPU clock
2017-04-16 Add kicad schematics
    [FASTUSBaspAdapter.kicad_pcb, FASTUSBaspAdapter.sch]
2017-04-16 Add gerber files
    [FASTUSBaspAdapter-B.Cu.gbl, FASTUSBaspAdapter-B.Mask.gbs, FASTUSBaspAdapter-B.SilkS.gbo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]
2017-04-16 Add page settings into schematic & pcb
    [FASTUSBaspAdapter.kicad_pcb, FASTUSBaspAdapter.sch]
2017-04-16 Add schematic & board png image
    sabor wanted it :)
2017-04-16 improve the design little bit
    [FASTUSBaspAdapter-B.Cu.gbl, FASTUSBaspAdapter-B.Mask.gbs, FASTUSBaspAdapter-B.SilkS.gbo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]
2017-04-16 Add kicad with standard 6 pin isp header
    Thanks to sabor for the idea.
    [FASTUSBaspAdapter-B.Cu.gbl, FASTUSBaspAdapter-B.Mask.gbs, FASTUSBaspAdapter-B.SilkS.gbo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]
2017-04-17 Add modified gerber files
    [FASTUSBaspAdapter-B.Cu.gbl, FASTUSBaspAdapter-B.Mask.gbs, FASTUSBaspAdapter-B.SilkS.gbo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]
2017-04-17 Add panelize pcb
    [FASTUSBaspAdapter.kicad_pcb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]
2017-04-18 Add better panilzed version 0.2
    [panelized.kicad_pcb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]
2017-05-21 Add kicad3 files
    [FASTUSBaspAdapter-B.Cu.gbl, FASTUSBaspAdapter-B.Mask.gbs, FASTUSBaspAdapter-B.SilkS.gbo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]
2017-08-07 Add support of openocd
    This trick is based on video https://www.youtube.com/watch?v=0eHpoPZvI3U
    at nuttX channel.
    This allows you to flash the board upto 128Kb size
    which is pretty cool.
2017-08-07 Add new kicad designed
    [FASTUSBaspAdapter-B.Cu.gbl, FASTUSBaspAdapter-B.Mask.gbs, FASTUSBaspAdapter-B.SilkS.gbo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]
2017-08-15 show the board at top
2017-08-18 Add support of serial upload using usb to uart converter.
2017-08-28 Add support of hse8mhz_out_48Mhz clock
    Earlier we were using hsi_out_48Mhz which has
    clock tolerance upto 1% which is higher than usb clock tolerance
    12.0+-0.03 Mb/s ~ 0.25
    Although i did not face any problems yet.
    Also HSI is temperature sensitive so its better to use HSE instead.
    libopencm3 does not have this function so write one and add it.
    This needs to be tested one time
    [main.c]
2017-10-09 use correct pullup code to avoid usb connection issues
    well, it works almost 90% of the time with usbdplus hack..
    but its better to have code for correct pullup code.
    [config.h, main.c]
2017-10-09 Add abt how to fix usb d+ pullup Resistor
2017-12-15 Add macro for spi bus and clock.
2017-12-15 Use SPI2 to communicate instead
    Since SPI1 is not 5V tolerant so its better to use
    SPI2 instead which is 5V tolerant.
    Also define all used clocks in one go at the begining.
2018-01-20 remove kicad.
    the kicad files are old and does not reperesent correct pinout diagram
    [FASTUSBaspAdapter-B.Cu.gbl, FASTUSBaspAdapter-B.Mask.gbs, FASTUSBaspAdapter-B.SilkS.gbo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]
2018-01-21 firmware: serial tx: fix the bug
    update the firmware binary as well.
    [main.cpp]
2018-01-25 firmware: implement 48Mhz clock and use it.
    Running clock at 48Mhz gives lower and stable SPI speed.
    The spi slave clock in AVR is F_CPU/4 (for spi master, its F/2)
    so a typical atmega328p running at 16Mhz can do 16/4 = 4 Mhz spi speed
    at max. Lets respect that.
    default: 48/16 = 3Mhz
    48/32 = 1.5Mhz and so on.
2018-01-27 add pcb files
    [fastusbasp_v2.kicad_pcb, fastusbasp_v2.sch]
2018-02-08 fix the cdc structure.
    [main.cpp]
2018-03-03 fix the compilation
    Make it compilable with latest libocm3 code.
    the control ep cb signature is changed.
    [main.cpp]
2018-04-30 disable rst, mosi & SS on isp disconnect.
    should fix https://github.com/amitesh-singh/FASTUSBasp/issues/5
    [isp.h]
2020-05-26 Fixed Composite Device Error on Windows OS
    [main.cpp]
2021-06-13 fix the compilation erorr.
    ref #6
    [main.cpp]
2023-08-17 fix(spi): remove spi_reset()
    libocm3 has removed this function
    [isp.h]
2025-09-07 fix a typo
    use ISP_BUS instead of hardcoded SPI1
    Thanks to Alexander Inyukhin for reporting
    [isp.h]

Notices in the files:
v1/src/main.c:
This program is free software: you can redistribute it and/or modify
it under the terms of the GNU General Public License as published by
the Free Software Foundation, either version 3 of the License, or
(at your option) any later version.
